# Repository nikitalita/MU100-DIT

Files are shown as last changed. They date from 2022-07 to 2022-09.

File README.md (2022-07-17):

# MU100-DIT

A modification for Yamaha synthesizers to add optical audio out.

This mod has been especially designed for: 
* Yamaha MU100
* Yamaha MU100R
* Yamaha MU90
* Yamaha MU90R

For these synths, a connector board has been designed that enables this mod to be installed with little-to-no board modification.

On the MU100/MU90, this involves soldering an unpopulated header and bridging some pads.

On the Rackmount versions of these, the MU100R/MU90R, this will plug in directly to the molex connector for the analog board, no board modification required:


The main board has been designed to fit within the limited back panel space on the MU100/MU90 and to not run into the MU100/MU100R's expansion cards.


## Schematics:

### Main board

kicad_DPyMCWLxIo

### MU100/MU90 Connector board




## Installation instructions:

For the Yamaha MU100/MU90, the DIF0 must be bridged, all others left floating.

**TODO: Rest of instructions**

## Other compatible synths
This includes the following synthesizers:

* Yamaha MU128
* Yamaha AN200

...and many others. This mod will work for any device that has a 16-bit, 18-bit, 20-bit, or 24-bit PCM/I2S data stream feeding into the DAC, and has a consistent sample rate of 32/44.1/48/88.2/96khz. If you would like to test this out on other devices, please feel free to submit a pull request detailing what device and what settings you set.

## Links:
* https://esher.ru/blog/887.html - The main inspiration for this design, special thanks to vetal!
* https://github.com/vetal-esher/18bit-DIT - Vetal's custom AK4103A board that is designed to use coax with a transformer instead of optical.
* https://kurohane.net/wiki/index.php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 (Japanese) - Another AK4103A optical mod, designed for the SC-88 pro.
* https://github.com/w-dee/AK4103A-DIT - Another, general purpose AK4103A DIT modification.

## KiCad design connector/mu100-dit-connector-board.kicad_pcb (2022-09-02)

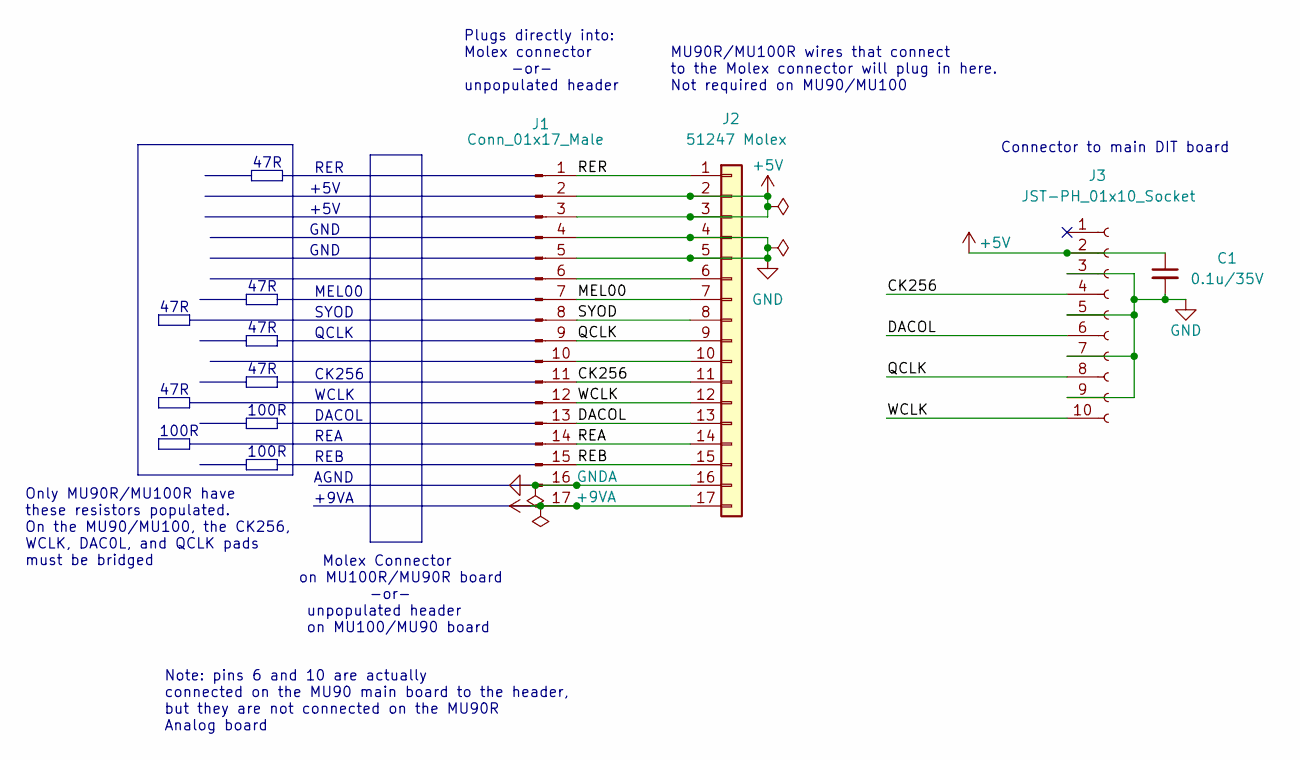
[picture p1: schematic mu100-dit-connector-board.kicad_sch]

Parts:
C1: 0.1u/35V; C_0805_2012Metric_Pad1.18x1.45mm_HandSolder
J1: Conn_01x17_Male; PinHeader_1x17_P2.00mm_Vertical
J2: 51247 Molex; Molex_Wire-Trap_52147-1710_1x17_P2.00mm_Vertical; Mfg. Part No. 0521471710; Mouser 538-52147-1710
J3: JST-PH_01x10_Socket; JST_PH_B10B-PH-K_1x10_P2.00mm_Vertical

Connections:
+5V: C1.1, J1.2, J1.3, J2.2, J2.3, J3.2
+9VA: J1.17, J2.17
/CK256: J1.11, J2.11, J3.4
/DACOL: J1.13, J2.13, J3.6
/MEL00: J1.7, J2.7
/QCLK: J1.9, J2.9, J3.8
/REA: J1.14, J2.14
/REB: J1.15, J2.15
/RER: J1.1, J2.1
/SYOD: J1.8, J2.8
/WCLK: J1.12, J2.12, J3.10
GND: C1.2, J1.4, J1.5, J2.4, J2.5, J3.3, J3.5, J3.7, J3.9
GNDA: J1.16, J2.16
unnamed: J1.6, J2.6
unnamed: J1.10, J2.10

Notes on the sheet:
100R
Only MU90R/MU100R have these resistors populated. On the MU90/MU100, the CK256, WCLK, DAC0L, and QCLK pads must be bridged
+5V
Note: pins 6 and 10 are actually connected on the MU90 main board to the header, but they are not connected on the MU90R Analog board
REB
47R
+9VA
CK256
SYOD
DACOL
GND
QCLK
Plugs directly into: Molex connector -or- unpopulated header
Molex Connector on MU100R/MU90R board -or- unpopulated header on MU100/MU90 board
MEL00
REA
RER
Connector to main DIT board
AGND
WCLK
MU90R/MU100R wires that connect to the Molex connector will plug in here. Not required on MU90/MU100

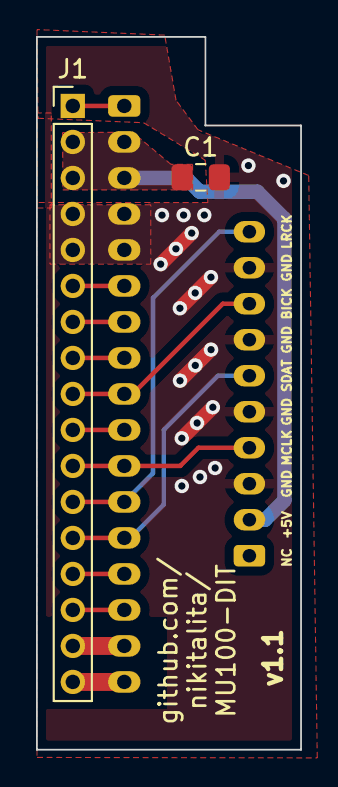
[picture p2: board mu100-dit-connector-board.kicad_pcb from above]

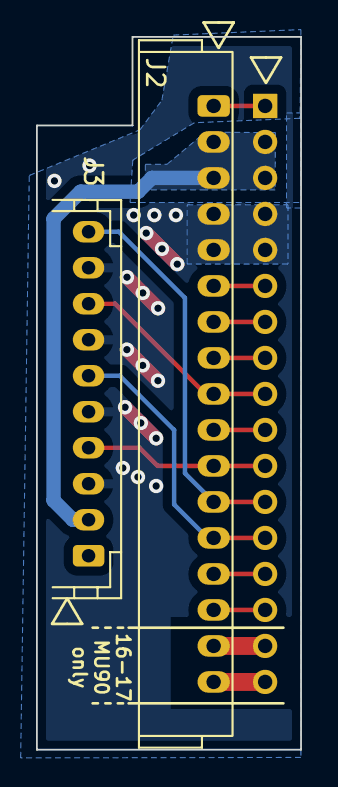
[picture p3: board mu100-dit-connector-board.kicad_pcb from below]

Board: 2 copper layers, 14.7 x 39.6 mm, 4 parts (2 on the bottom side), 15 nets.

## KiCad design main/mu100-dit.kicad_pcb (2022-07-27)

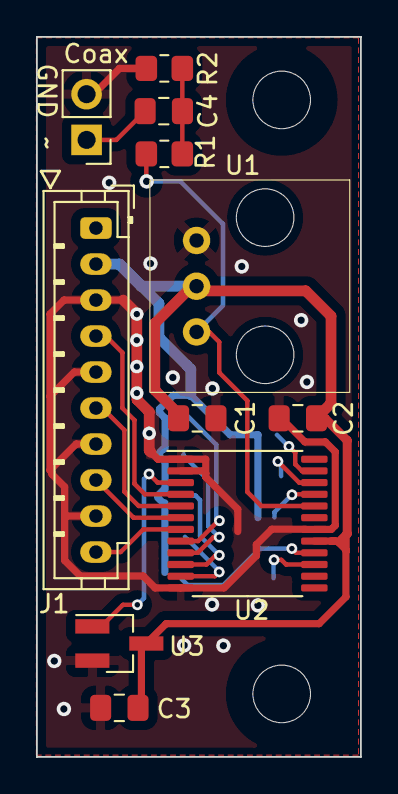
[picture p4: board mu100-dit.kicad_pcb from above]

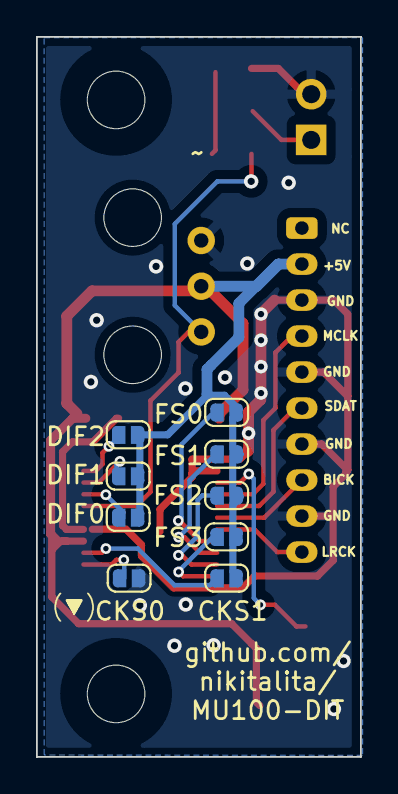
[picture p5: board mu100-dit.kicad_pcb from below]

Board: 2 copper layers, 18.0 x 40.0 mm, 22 parts (9 on the bottom side), 19 nets.

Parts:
C1, C2, C3, C4: 0.1uF; C_0805_2012Metric_Pad1.18x1.45mm_HandSolder
H1, H2: MountingHole_Pad; MountingHole_3.2mm_M3_ISO7380
J1: Conn_01x10_Female; JST_PH_B10B-PH-K_1x10_P2.00mm_Vertical
J2: Conn_01x02_Male; PinHeader_1x02_P2.54mm_Vertical
JP1, JP2, JP3, JP4, JP5, JP6, JP7, JP8, JP9: Jumper_NO_Small; SolderJumper-Open_RoundedPad-custom
R1: 330; R_0805_2012Metric_Pad1.20x1.40mm_HandSolder
R2: 100; R_0805_2012Metric_Pad1.20x1.40mm_HandSolder
U1: TOTX-177L; Toshiba_TOTX177
U2: AK4103A; TSSOP-24_6.1x7.8mm_P0.65mm
U3: APX809S-46SR-7; SOT-23_Handsoldering

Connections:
+5V: C1.2, C2.2, C3.2, J1.2, JP1.1, JP2.1, JP3.1, JP4.1, JP5.1, JP6.1, JP7.1, JP9.1, U1.2 (VCC), U2.17 (VDD), U3.3 (VCC)
/BICK: J1.8, U2.6 (BICK)
/CKS0: JP8.2, U2.15 (CKS0)
/CKS1: JP9.2, U2.16 (CKS1)
/DIF0: JP5.2, U2.21 (DIF0)
/DIF1: JP6.2, U2.22 (DIF1)
/DIF2: JP7.2, U2.23 (DIF2)
/FS0: JP1.2, U2.8 (FS0/CSN)
/FS1: JP2.2, U2.9 (FS1/CDTI)
/FS2: JP3.2, U2.10 (FS2/CCLK)
/FS3: JP4.2, U2.11 (FS3/CDTO)
/LRCK: J1.10, U2.7 (LRCK)
/MCLK: J1.4, U2.4 (MCLK)
/RESET: U2.3 (PDN), U3.1 (~RESET)
/SDAT: J1.6, U2.5 (SDTI)
/TXP: R1.1, U1.3 (Input), U2.20 (TXP)
GND: C1.1, C2.1, C3.1, J1.3, J1.5, J1.7, J1.9, J2.2, JP8.1, R2.1, U1.1 (GND), U2.1 (V1), U2.2 (TRANS), U2.12 (C1), U2.18 (VSS), U3.2 (GND)
unnamed: C4.1, R1.2, R2.2
unnamed: C4.2, J2.1

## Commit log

2022-07-01 remove temp files
    [mu100-dit-bak.kicad_pcb, mu100-dit-new-backup.kicad_pcb]
2022-07-01 fix issue with totx177 footprint, fix schematics
    [mu100-dit.kicad_pcb, mu100-dit.kicad_sch]
2022-07-01 update gerbers
    [mu100-dit-CuBottom.gbr, mu100-dit-CuTop.gbr, mu100-dit-EdgeCuts.gbr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]
2022-07-01 add jumpers to board
    [mu100-dit.kicad_pcb, mu100-dit.kicad_sch]
2022-07-02 Add connector board
    [BOM-mu100-dit.csv, User Library-GP1FAV50TK_e_1.STEP, User Library-TORX147L-1.STEP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]
2022-07-03 Add reset circuit, remove need for reset
    [mu100-dit-CuBottom.gbr, mu100-dit-CuTop.gbr, mu100-dit-EdgeCuts.gbr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]
2022-07-03 Update screw hole position
    [mu100-dit-CuBottom.gbr, mu100-dit-CuTop.gbr, mu100-dit-EdgeCuts.gbr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]
2022-07-03 Move reset circuit to other side of board
    [mu100-dit-CuBottom.gbr, mu100-dit-CuTop.gbr, mu100-dit-EdgeCuts.gbr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]
2022-07-04 Add header for optional coax output
    [mu100-dit-CuBottom.gbr, mu100-dit-CuTop.gbr, mu100-dit-EdgeCuts.gbr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]
2022-07-04 finish connector pcb
    [mu100-dit-connector-board-CuBottom.gbr, mu100-dit-connector-board-CuTop.gbr, mu100-dit-connector-board-EdgeCuts.gbr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]
2022-07-05 combine pcb projects
    [MU100-dit-connector-board.kicad_sch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]
2022-07-05 fix coax placement
    [mu100-dit-B_Cu.gbl, mu100-dit-B_Mask.gbs, mu100-dit-B_Paste.gbp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]
2022-07-17 undo merge, panelize connector board
    [mu100-dit-B_Cu.gbl, mu100-dit-B_Mask.gbs, mu100-dit-B_Paste.gbp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]
2022-07-17 Cleanup files, no board changes
    [10_mu100-dit-NPTH.drl, 11_mu100-dit-PTH.drl, 13_mu100-dit-connector-board-B_Cu.gbl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]
2022-07-17 Add schematics
2022-07-17 Clean up schematics and board drawings
    [mu100-dit-CuBottom.gbr, mu100-dit-CuTop.gbr, mu100-dit-EdgeCuts.gbr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]
2022-07-20 Unground mounting holes, rearrange DIF0/DIF1 vias to avoid bridge
    [mu100-dit-CuBottom.gbr, mu100-dit-CuTop.gbr, mu100-dit-EdgeCuts.gbr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]
2022-07-27 minor tweaks to main board
    [mu100-dit-CuBottom.gbr, mu100-dit-CuTop.gbr, mu100-dit-EdgeCuts.gbr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]
2022-07-28 remove terminating resistors on connector board
    [mu100-dit-connector-board-CuBottom.gbr, mu100-dit-connector-board-CuTop.gbr, mu100-dit-connector-board-EdgeCuts.gbr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]
2022-09-02 FInal board revision
    [mu100-dit-CuBottom.gbr, mu100-dit-CuTop.gbr, mu100-dit-EdgeCuts.gbr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]

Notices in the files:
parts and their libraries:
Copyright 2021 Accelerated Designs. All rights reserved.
